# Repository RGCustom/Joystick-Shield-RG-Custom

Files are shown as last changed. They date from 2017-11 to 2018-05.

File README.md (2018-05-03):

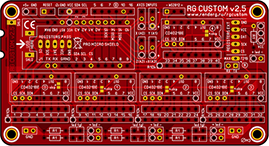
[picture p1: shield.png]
Shieldpic


# Joystick Shield RG Custom v2.0
Joystick shield for Arduino Pro Micro with shift registers, i2c text LCD and ws2812 led support.
RG Custom PCB  shield allows you to easy create your own control panel, throttle or joystick device. 
Shield PCB size is 95x52 mm

Controller supports: 4 analogue inputs (6 max), 40 digital inputs. Pushbuttons, toggle switches with pulse, rotary encoders, pov hats.
i2c text LCD displays. ws2812 leds.

### To build it you will need.
1. Shield PCB
2. Arduino pro micro
3. 5pcs CD4021BE shift registers
4. 5pcs 10kOhm sip9 array resistors.
5. 2.54mm Male PCB Single Row Straight Header Strip Connectors. 
6. 1kOhm resistors for leds.

Arduino IDE 1.6.6 (or above) library that adds a joystick to the list of HID devices. This will not work with Arduino IDE 1.6.5 (or below).

### You will need to install 3 additional libraries:
Info on how to install additional libraries can be found here.
https://www.arduino.cc/en/Guide/libraries#toc4

### Libraries included as submodules.
Arduino Joystick library ver 1.0  
LiquidCrystal_I2C  
Adafruit_NeoPixel  

### Link on PCB in OSH Park https://oshpark.com/shared_projects/YERseqpP

### You also can build your own shield, using breadboard.
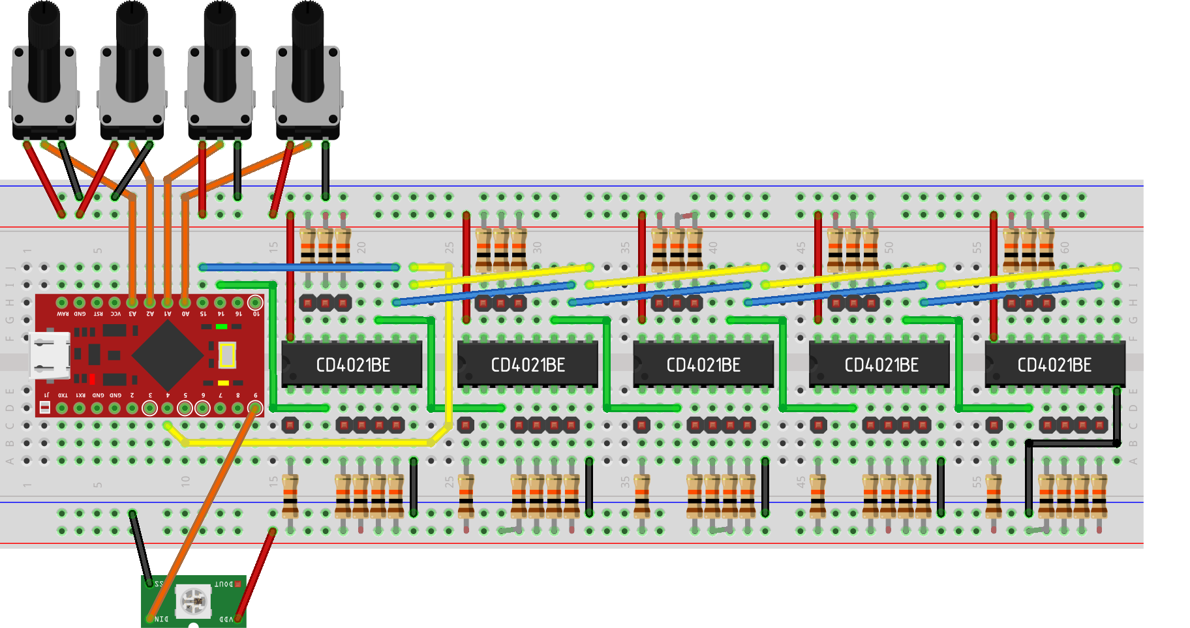
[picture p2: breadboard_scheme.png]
breadboard pic


Buttons (or toggle switches) all have common ground and connected to pins between shift register and resistor.
Instead of 5pcs 10kOhm sip9 array resistors use 40pcs 10kOhm resistors. 

## Contacts section:
Facebook https://www.facebook.com/RGcustom/  
RG Custom Discord channel https://discord.gg/tjndHQ7  
E-Mail: rgcustm@gmail.com  
IL-2 Forums (russian): https://forum.il2sturmovik.ru/topic/6511-opensource-kontroller-na-arduino/  
StarCitizen Spectrum thread: https://robertsspaceindustries.com/spectrum/community/SC/forum/50264/thread/open-source-arduino-controller-for-control-panels

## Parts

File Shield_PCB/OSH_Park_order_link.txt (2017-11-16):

https://oshpark.com/shared_projects/YERseqpP

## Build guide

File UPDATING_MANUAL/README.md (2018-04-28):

This is a short and easy manual on how to load joystick sketch to your Arduino board.
# STEP 1
Follow this link to https://www.arduino.cc and download and install latest Arduino IDE software
### First select SOFTWAREand choose DOWNLOADS
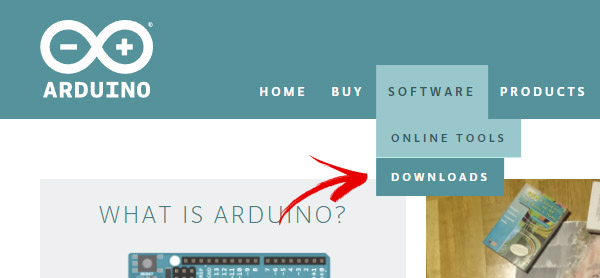
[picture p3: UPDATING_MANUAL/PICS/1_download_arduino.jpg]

### Then select Windows installer
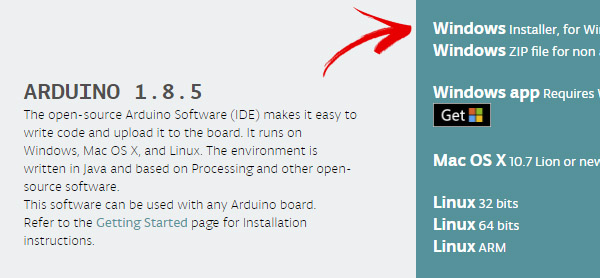
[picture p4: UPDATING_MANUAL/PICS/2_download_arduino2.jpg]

### Install Arduino IDE, following installer instructions.

# STEP 2
Go to Joystick Shield main GitHub directory https://github.com/RGCustom/Joystick-Shield-RG-Custom and download firmware sketches
### First click on Clone or Download green buttons and select Download .ZIP
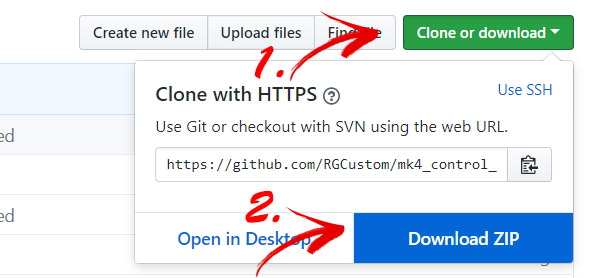
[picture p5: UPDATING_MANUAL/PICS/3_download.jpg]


# STEP 3
Now download and install needed libraries 
### Libraries, included as submodules wont download on previous step, so they must be downloaded separately.
### Clicking on library will lead you to its location.
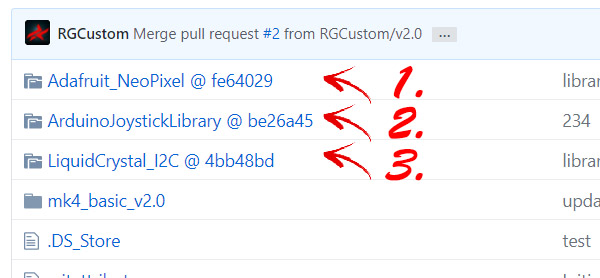
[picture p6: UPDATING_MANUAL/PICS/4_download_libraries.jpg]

### Click Branch button and select master to get the latest library.
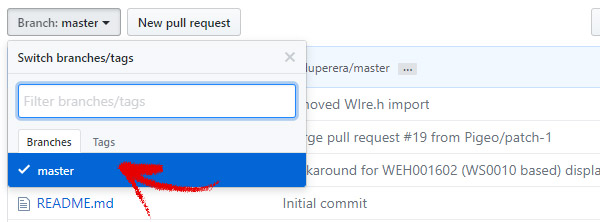
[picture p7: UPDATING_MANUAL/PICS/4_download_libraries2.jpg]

### Donwload library same as you downloaded main sketch.
Step2
### Install librariesin your arduino libraries folder.
Arduino manual on installing libraries https://www.arduino.cc/en/Guide/Libraries#toc2
### ArduinoJoystick library has a default installation bat file. 
Default libraries location (you can just unzip them there) is C:\Users\ your user name \Documents\Arduino\libraries
or just go to My Documents > Arduino > libraries

# STEP 4
### Unzip main sketch you downloaded in to a folder.
Select folder with a proper firmware sketch (names may vary)
### Open sketch .INO file. 
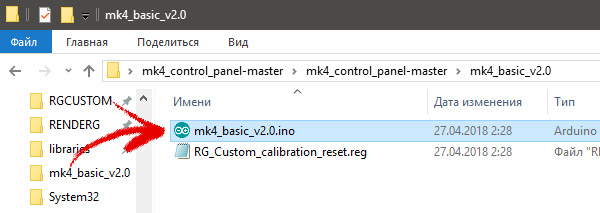
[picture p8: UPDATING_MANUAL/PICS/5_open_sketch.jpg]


Arduino IDE will open sketch.
### Open Tools menu and select Board -> Arduino Leonardo
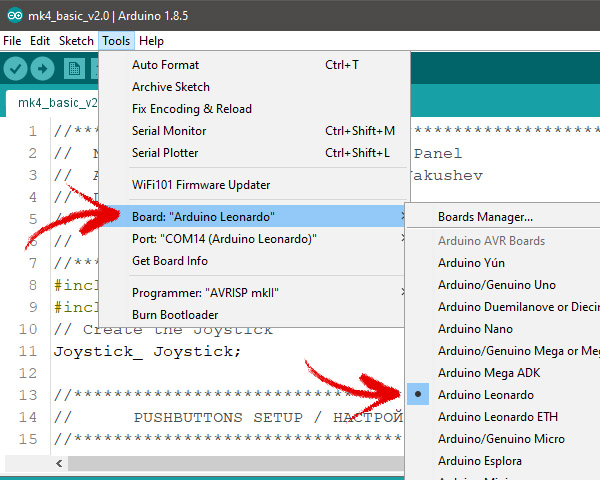
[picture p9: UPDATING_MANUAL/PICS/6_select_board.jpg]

### Also select corresponding port number in same menu.
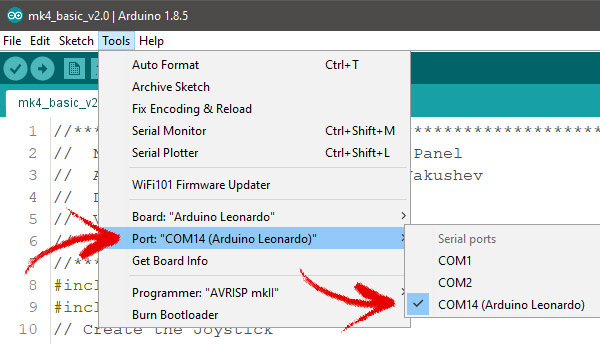
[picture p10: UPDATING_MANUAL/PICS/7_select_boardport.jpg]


# STEP 5
Prepare Arduino IDE to upload firmware.
### Select Preferences from File menu
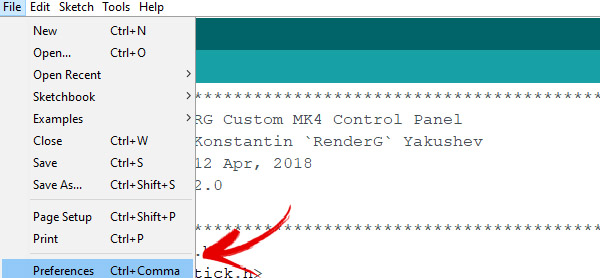
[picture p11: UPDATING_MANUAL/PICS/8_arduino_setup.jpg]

### And in Preferences window mark "Show verbose otput during: upload" checkbox
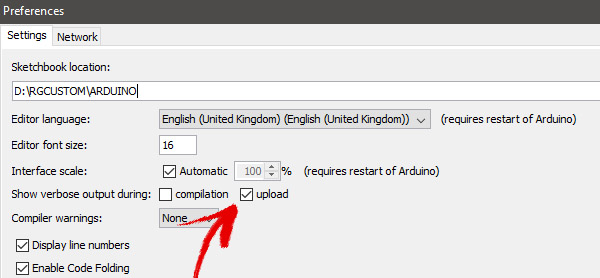
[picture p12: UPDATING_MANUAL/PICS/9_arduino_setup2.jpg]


# STEP 6
### Verify sketch by pressing VERIFY button
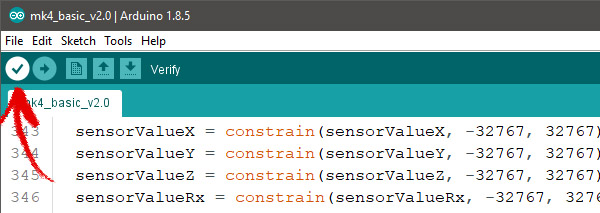
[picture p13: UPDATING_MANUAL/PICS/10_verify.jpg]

#### If everything is Ok, you will see smth like this
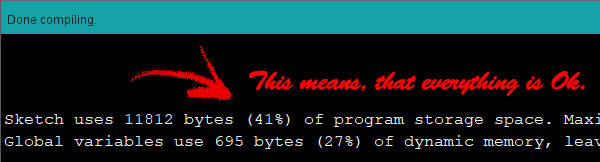
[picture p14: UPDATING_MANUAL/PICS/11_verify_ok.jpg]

### After that hit upload button
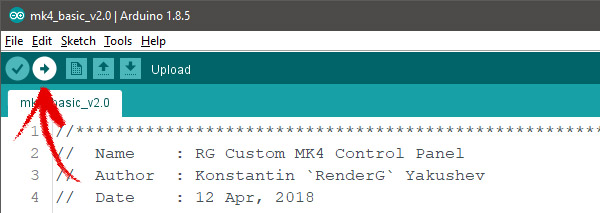
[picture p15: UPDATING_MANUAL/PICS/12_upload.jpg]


# STEP 7 -= SKIP THIS STEP IF YOU UPLOADING CODE FIRST TIME TO YOUR ARDUINO =-
#### After firmware will compile, Arduino IDE will start looking for controller in bootloader state
### And will start scanning ports for arduino, showing smth like
PORTS {COM1, COM2, COM14, } / {COM1, COM2, COM14, } => {}
PORTS {COM1, COM2, COM14, } / {COM1, COM2, COM14, } => {}
### This is when you have to push RESET button o the back of your device.
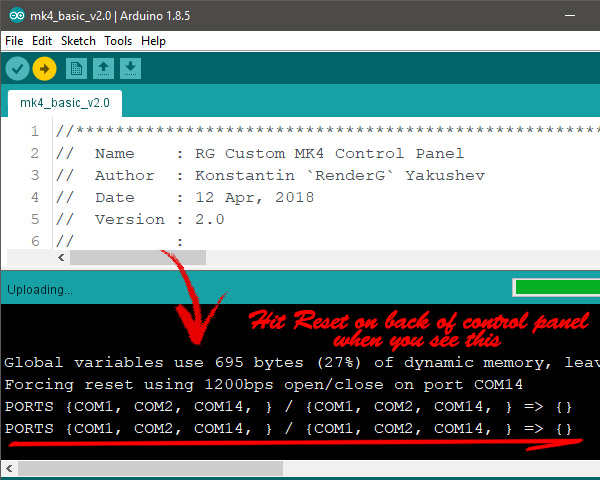
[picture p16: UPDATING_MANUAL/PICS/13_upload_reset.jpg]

### After upload will be finished, your device will reboot and will be updated.
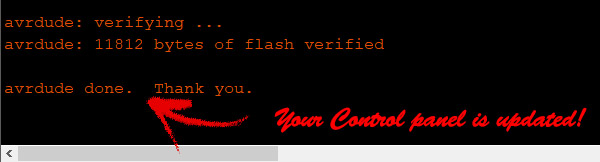
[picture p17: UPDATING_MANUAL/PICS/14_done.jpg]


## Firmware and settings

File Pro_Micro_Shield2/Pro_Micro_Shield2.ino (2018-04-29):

//**************************************************************//
//  Name    : RG Custom Pro Micro shield code                       //
//  Author  : Konstantin `RenderG` Yakushev                     //
//  Date    : 28 Apr, 2018                                      //
//  Version : 2.0                                               //
//          :                                                   //
//****************************************************************
#include <Wire.h>
#include <Joystick.h>
#include <LiquidCrystal_I2C.h>
#include <Adafruit_NeoPixel.h>
LiquidCrystal_I2C lcd(0x3F, 16, 2); // lcd setup
// Create the Joystick
Joystick_ Joystick;
// Which pin on the Arduino is connected to the NeoPixels?
// On a Trinket or Gemma we suggest changing this to 1
#define PIN            A9

// How many NeoPixels are attached to the Arduino?
#define NUMPIXELS      16

// When we setup the NeoPixel library, we tell it how many pixels, and which pin to use to send signals.
// Note that for older NeoPixel strips you might need to change the third parameter--see the strandtest
// example for more information on possible values.
Adafruit_NeoPixel pixels = Adafruit_NeoPixel(NUMPIXELS, PIN, NEO_GRB + NEO_KHZ800);

//**************************************************
//      PUSHBUTTONS SETUP / НАСТРОЙКА КНОПОК
//**************************************************
const int PBnum = 22;        // Number of pushbuttons / количество кнопок
int PBreg[] = {1,1,1,1,1,1,1,1,1,2,2,2,2,2,2,2,3,3,3,3,3,3}; // shiftregisters with pushbuttons / регистры с кнопками
int PBpin[] = {0,1,2,3,4,5,6,7,0,1,2,3,4,5,6,7,0,1,2,3,4,5}; // shiftregister pins with pushbuttons / ножки регистров с кнопками
int PBstate[PBnum]; // State of pushbuttons / состояние кнопок (для индикации)

//**************************************************
//  TOGGLE SWITCHES SETUP / НАСТРОЙКА ТУМБЛЕРОВ
//**************************************************
const int TGnum = 10;        // Number of toggle switches / количество тумблеров
int TGreg[] = {3,3,4,4,4,4,4,4,4,4}; // shiftregisters with toggleswitches / регистры с тумблерами
int TGpin[] = {6,7,0,1,2,3,4,5,6,7}; // shiftregister pins with toggleswitches / ножки регистров с тумблерами
int TGstate[TGnum]; // State of toggle switches (for indication on LCD or leds) / состояние тумблеров (для индикации)
int TGdelay(15); // Toggle switch pulse duration in ms / длинна импульса тумблера

//**************************************************
//       HATS SETUP / НАСТРОЙКА ХАТОК
//**************************************************
const int HATnum = 4;        // Number of POV HAT switches (one POV hat is 4 buttons, so multiply by 4) / количество хаток. Одна хатка - 4 кнопки, так что умножайте на 4.
int HATreg[] = {5,5,5,5}; // shiftregisters with hatswitches / регистры с хатками
int HATpin[] = {0,1,2,3}; // shiftregister pins with hatswitches / ножки регистров с хатками
int HATstate[HATnum]; // State of POV HAT switches (for indication on LCD or leds) / состояние хаток (для индикации)

//**************************************************
//      ENCODERS SETUP / НАСТРОЙКА ЭНКОДЕРОВ
//**************************************************
const int ENCnum = 2;        // Number of rotary encoders (each encoder L+R turns counts as one) / количество энкодеров. 
int ENCregA[] = {5,5}; // shiftregisters with encoders direction A / регистры с энкодерами с вращением в сторону А
int ENCpinA[] = {4,7}; // shiftregister pins encoders direction A / регистры с энкодерами с вращением в сторону B
int ENCregB[] = {5,5}; // shiftregisters with encoders direction B / регистры с энкодерами с вращением в сторону B
int ENCpinB[] = {5,6}; // shiftregister pins encoders direction B / ножки регистров с энкодерами с вращением в сторону B
int ENCA[ENCnum]; 
int ENCB[ENCnum]; 
int ENC_Aprev[ENCnum];  
int ENCtime[] = {4,4}; // Encoders timing in ms. increase for slower and decrease for faster. Тайминги энкодеров
unsigned long loopTime;


// Set to true to test "Auto Send" mode or false to test "Manual Send" mode.
const bool initAutoSendState = true;
//const bool initAutoSendState = false;

uint8_t joystickType = 0x08; // Default: 0x03 - Indicates the joystick's HID report ID. This value must be unique if you are creating multiple instances of Joystick. Do not use 0x01 or 0x02 as they are used by the built-in Arduino Keyboard and Mouse libraries.
uint8_t buttonCount = 32; //Button count
uint8_t hatSwitchCount = 2;


//**************************************************
//        AXIS INPUTS SETUP / НАСТРОЙКА ОСЕЙ
//**************************************************
const int xAxisFilter = 4;         // smoothing for X axis
const int yAxisFilter = 4;         // smoothing for Y axis
const int zAxisFilter = 4;         // smoothing for Z axis
const int rXAxisFilter = 4;        // smoothing for rX axis

int xAxisRead[xAxisFilter];         // readings for X axis
int yAxisRead[yAxisFilter];         // readings for Y axis
int zAxisRead[zAxisFilter];         // readings for Z axis
int rXAxisRead[rXAxisFilter];        // readings for rX axis

int xAxisIndex = 0;         // the index of the currentreadings for X axis
int yAxisIndex = 0;         // the index of the currentreadings for Y axis
int zAxisIndex = 0;         // the index of the currentreadings for Z axis
int rXAxisIndex = 0;        // the index of the currentreadings for rX axis

long xAxisTotal = 0;         // the running total for X axis
long yAxisTotal = 0;         // the running total for Y axis
long zAxisTotal = 0;         // the running total for Z axis
long rXAxisTotal = 0;        // the running total for rX axis

int xAxisAverage = 0;         // the average for X axis
int yAxisAverage = 0;         // the average for Y axis
int zAxisAverage = 0;         // the average for Z axis
int rXAxisAverage = 0;        // the average for rX axis

const int xAxis = A0;         // analog sensor for X axis
const int yAxis = A3;         // analog sensor for Y axis
const int zAxis = A2;         // analog sensor for Z axis
const int rXAxis = A1;        // analog sensor for rX axis

bool includeXAxis = true; //Indicates if the X Axis is available on the joystick.
bool includeYAxis = true; //Indicates if the Y Axis is available on the joystick.
bool includeZAxis = true; //Indicates if the Z Axis (in some situations this is the right X Axis) is available on the joystick.
bool includeRxAxis = true; //Indicates if the X Axis Rotation (in some situations this is the right Y Axis) is available on the joystick.
bool includeRyAxis = false; //Indicates if the Y Axis Rotation is available on the joystick.
bool includeRzAxis = false; //Indicates if the Z Axis Rotation is available on the joystick.
bool includeRudder = false; //Indicates if the Rudder is available on the joystick.
const int CalibrationPin = 8; // calibration toggle switch

// axis calibration variables:
int16_t sensorValueX = 0;         // the sensor X value
int sensorValueY = 0;         // the sensor Y value
int sensorValueZ = 0;         // the sensor Z value
int sensorValueRx = 0;        // the sensor Rx value
int sensorValueRy = 0;        // the sensor Rx value
int sensorValueRz = 0;        // the sensor Rx value

int sensorMinX = 0;           // minimum sensor value
int sensorMaxX = 1;         // maximum sensor value
int sensorMinY = 0;           // minimum sensor value
int sensorMaxY = 1;         // maximum sensor value
int sensorMinZ = 0;           // minimum sensor value
int sensorMaxZ = 1;         // maximum sensor value
int sensorMinRx = 0;           // minimum sensor value
int sensorMaxRx = 1;         // maximum sensor value
int sensorMinRy = 0;           // minimum sensor value
int sensorMaxRy = 1;         // maximum sensor value
int sensorMinRz = 0;           // minimum sensor value
int sensorMaxRz = 1;         // maximum sensor value*/


// variables will change:
int CalibrationState = 0;     // variable for reading calibration status

//**************************************************
//              SHIFT REGISTERS SETUP
//**************************************************
int latchPin = 4;
int dataPin = 14;
int clockPin = 15;

//Define number of registers
int num_registers = 5;

//Define array to hold the data
//for each shift register.

byte switchVar[] = {72, 73, 74, 75, 76};  //01001000,01001001,01001010,01001011,01001100

//Define array to hold the state
//for each shift register.

byte switchState[] = {72, 73, 74, 75, 76};  //01001000,01001001,01001010,01001011,01001100
byte lastState[] = {72, 73, 74, 75, 76};  //01001000,01001001,01001010,01001011,01001100


//**************************************************
//              DEBOUNCE SETUP
//**************************************************
// the following variables are unsigned long's because the time, measured in miliseconds,
// will quickly become a bigger number than can be stored in an int.

unsigned long lastDebounceTime = 0;  // the last time the output pin was toggled
unsigned long debounceDelay = 5;    // the debounce time; increase if the output flickers

//define an array that has a place for the values of

byte settingVal[] = {  1, 1, 1, 1, 1, 1, 1, 1};

unsigned long lastlooptime = 0;  // the last time the output pin was toggled
unsigned long looptime = 0;    // the debounce time; increase if the output flickers




void setup() {
  //start serial
 // Serial.begin(9600);

  //start Joystick
  Joystick.begin(initAutoSendState);
  
 //defining axis ranges
  Joystick.setXAxisRange(-32768, 32767);
  Joystick.setYAxisRange(-32768, 32767); 
  Joystick.setZAxisRange(-32768, 32767); 
  Joystick.setRxAxisRange(-32768, 32767);
  Joystick.setRyAxisRange(-32768, 32767);
  Joystick.setRzAxisRange(-32768, 32767); 
//  Joystick.setRudderAxisRange(0, 1023);
//  Joystick.setThrottleAxisRange(0, 1023); 

  //define pin modes
  pinMode(latchPin, OUTPUT);
  pinMode(clockPin, OUTPUT);
  pinMode(dataPin, INPUT);
 
  pixels.begin(); // This initializes the NeoPixel library.

//**************************************************
//              LCD INITIALISING STRING
//**************************************************
  lcd.init();
  lcd.backlight();// Enable LCD backlight
}

void loop() {
  looptime = millis();

//**************************************************
//              READING SHIFT REGISTERS
//**************************************************
  //Pulse the latch pin:
  //set it to 1 to collect parallel data
  digitalWrite(latchPin, 1);
  //set it to 1 to collect parallel data, wait
  //delayMicroseconds(20);
  //set it to 0 to transmit data serially
  digitalWrite(latchPin, 0);

  //while the shift register is in serial mode
  //collect each shift register into a byte
  //the register attached to the chip comes in first
  for (int z = 1; z <= num_registers; z++) {
    switchVar[z] = shiftIn(dataPin, clockPin);
  }
// *************************************************
//     PUSH BUTTONS SECTION
// *************************************************
    for (int i = 0; i <= (PBnum - 1); i++) {
      if (bitRead(switchVar[PBreg[i]], PBpin[i]) != bitRead(lastState[PBreg[i]], PBpin[i])) {
          // reset the debouncing timer
          lastDebounceTime = millis();
         }
         if ((millis() - lastDebounceTime) > debounceDelay) {
           // whatever the reading is at, it's been there for longer
           // than the debounce delay, so take it as the actual current state:
           // if the button state has changed:
           if (bitRead(switchVar[PBreg[i]], PBpin[i]) != bitRead(switchState[PBreg[i]], PBpin[i])) {
             switchState[PBreg[i]] = switchVar[PBreg[i]];
             // activate button if the new button state ON or OF
             if (bitRead(switchState[PBreg[i]], PBpin[i]) < 1) {
               //action on button press
               Joystick.setButton(i,1);
               //lcd.setCursor(1, 1);
               //lcd.print("ON");
               PBstate[i] = 1;
               }
              else {
               //action on button release
               Joystick.setButton(i,0);
               //lcd.setCursor(1, 1);
               //lcd.print("OFF");
               PBstate[i] = 0;
             }
            }
          }
        lastState[PBreg[i]] = switchVar[PBreg[i]];
       }
// *************************************************
//     PUSH BUTTONS SECTION ENDS HERE
// *************************************************

// *************************************************
//     TOGGLE SWITCHES SECTION
// *************************************************
    for (int i = 0; i <= (TGnum - 1); i++) {
      if (bitRead(switchVar[TGreg[i]], TGpin[i]) != bitRead(lastState[TGreg[i]], TGpin[i])) {
          // reset the debouncing timer
          lastDebounceTime = millis();
         }
         if ((millis() - lastDebounceTime) > debounceDelay) {
           // whatever the reading is at, it's been there for longer
           // than the debounce delay, so take it as the actual current state:
           // if the button state has changed:
           if (bitRead(switchVar[TGreg[i]], TGpin[i]) != bitRead(switchState[TGreg[i]], TGpin[i])) {
             switchState[TGreg[i]] = switchVar[TGreg[i]];
             // activate button if the new button state ON or OF
             if (bitRead(switchState[TGreg[i]], TGpin[i]) < 1) {
               //action on button press
               Joystick.setButton(i + PBnum,1);
               TGstate[i] = 1;
               //lcd.setCursor(1, 1);
               //lcd.print("ON");
               delay(TGdelay);
               Joystick.setButton(i + PBnum,0);
               }
              else {
               //action on button release
               Joystick.setButton(i + PBnum,1);
               //lcd.setCursor(1, 1);
               //lcd.print("OFF");
               delay(TGdelay);
               TGstate[i] = 0;
               Joystick.setButton(i + PBnum,0);
             }
            }
          }
        lastState[TGreg[i]] = switchVar[TGreg[i]];
       }
// *************************************************
//     TOGGLE SWITCH SECTION ENDS HERE
// *************************************************     

// *********************************************************
//     POV HATS SECTION Hats can have 9 positions.
//     -1 (nothing pressed) + degrees 0-315 with step of 45.
// *********************************************************
    for (int i = 0; i <= (HATnum - 1); i++) {
      if (bitRead(switchVar[HATreg[i]], HATpin[i]) != bitRead(lastState[HATreg[i]], HATpin[i])) {
          // reset the debouncing timer
          lastDebounceTime = millis();
         }
         if ((millis() - lastDebounceTime) > debounceDelay) {
           // whatever the reading is at, it's been there for longer
           // than the debounce delay, so take it as the actual current state:
            // if the button state has changed:
           if (bitRead(switchVar[HATreg[i]], HATpin[i]) != bitRead(switchState[HATreg[i]], HATpin[i])) {
             switchState[HATreg[i]] = switchVar[HATreg[i]];
             // activate button if the new button state ON or OF
             if (bitRead(switchState[HATreg[i]], HATpin[i]) < 1) {
               //action on button press
               Joystick.setHatSwitch(0, ((i + 1) * 90));
               HATstate[i] = ((i + 1) * 90);
               }
              else {
               //action on button release
               Joystick.setHatSwitch(0, -1);
               HATstate[i] = -1;
             }
            }
          }
        lastState[HATreg[i]] = switchVar[HATreg[i]];
       }
// *************************************************
//     HATS SECTION ENDS HERE
// *************************************************

// *************************************************
//     ENCODERS SECTION
// *************************************************
   for (int i = 0; i <= (ENCnum - 1); i++) {
      ENCA[i] = bitRead(switchVar[ENCregA[i]], ENCpinA[i]);     // Reads encoder state A 
      ENCB[i] = bitRead(switchVar[ENCregB[i]], ENCpinB[i]);     // Reads encoder state B 
       if((!ENCA[i]) && (ENC_Aprev[i])){    // If state changes
       if(ENCB[i]) {
        //Encoder rotates A
        Joystick.setHatSwitch(1, (i * 90));
        delay(ENCtime[i]);
        Joystick.setHatSwitch(1, -1);
       }   
       else { 
        //Encoder rotates B
        Joystick.setHatSwitch(1, ((i * 90)+180));
        delay(ENCtime[i]);
        Joystick.setHatSwitch(1, -1);
       }  
      }     
      ENC_Aprev[i] = ENCA[i];     // Save A state  
     }
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

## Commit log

2017-11-17 PCB preview update
2018-04-29 filter update
